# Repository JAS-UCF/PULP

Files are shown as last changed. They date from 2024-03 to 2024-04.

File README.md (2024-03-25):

# PULP

KiCAD project that contains a PCB layout, in hopes of over-optimizing the GNOR race

## Gameplan

implement a basic RP2040 board

- RP2040 processor *DONE*
- compass module *DONE*
- GPS module *DONE*
- PINOUT for I2C Bus 0 & 1 *DONE*
- PINOUT for PWM out Motor_Left & Motor_Right (2x3 Pins) *DONE*
- PINOUT for 3S Battery Power (External) ; Need to add regulator to help power the board *DONE*
- PINOUT for 6 GPIO pins *DONE*
- USB-C for programming and power *DONE*

## Questions?

Join the JAS Discord : <https://discord.gg/rzfwvgsg3Z>
Ask @ Peter about the project!

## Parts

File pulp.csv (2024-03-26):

Source: | /home/shitta/projects/PULP/pulp.kicad_sch
Date: | Tue 26 Mar 2024 07:26:22 PM EDT
Tool: | Eeschema 7.0.8-7.0.8~ubuntu22.04.1
Generator: | /usr/share/kicad/plugins/bom_csv_grouped_by_value.py
Component Count: | 71
Collated Components:
Item | Qty | Reference(s) | Value | LibPart | Footprint | Datasheet | DNP | Availability | Check_prices | Description | MF | MP | PROD_ID | Package | Price | SF_ID | SnapEDA_Link
1 | 2 | C1, C3 | 0.1uF | Device:C | Capacitor_SMD:C_0201_0603Metric | ~
2 | 3 | C2, C5, C7 | 4.7uF | Device:C | Capacitor_SMD:C_0201_0603Metric | ~
3 | 1 | C4 | 10nF | Device:C | Capacitor_SMD:C_0201_0603Metric | ~
4 | 18 | C6, C8, C9, C10, C15, C16, C17, C18, C19, C20, C21, C22, C23, C24, C25, C26, C27, C28 | 1uF | Device:C | Capacitor_SMD:C_0201_0603Metric | ~
5 | 2 | D1, D2 | ESD9B5.0ST5G | Diode:ESD9B5.0ST5G | Diode_SMD:D_SOD-923 | https://www.onsemi.com/pub/Collateral/ESD9B-D.PDF
6 | 1 | D3 | LED_ARGB | Device:LED_ARGB | LED_SMD:LED_RGB_1210 | ~
7 | 1 | J1 | Conn_Coaxial | Connector:Conn_Coaxial | Connector_Coaxial:SMA_Amphenol_901-143_Horizontal | ~
8 | 2 | J2, J3 | Conn_01x02_Pin | Connector:Conn_01x02_Pin | Connector_PinHeader_2.54mm:PinHeader_1x02_P2.54mm_Horizontal | ~
9 | 2 | J4, J5 | Conn_01x03_Pin | Connector:Conn_01x03_Pin | Connector_PinHeader_2.54mm:PinHeader_1x03_P2.54mm_Horizontal | ~
10 | 1 | J6 | Conn_01x09_Pin | Connector:Conn_01x09_Pin | Connector_PinHeader_2.54mm:PinHeader_1x09_P2.54mm_Vertical | ~
11 | 1 | J7 | USB_C_Receptacle | Connector:USB_C_Receptacle | Connector_USB:USB_C_Receptacle_CNCTech_C-ARA1-AK51X | https://www.usb.org/sites/default/files/documents/usb_type-c.zip
12 | 1 | J8 | Conn_01x02_Pin | Connector:Conn_01x02_Pin | Connector_AMASS:AMASS_XT60-F_1x02_P7.20mm_Vertical | ~
13 | 1 | L1 | 27nH | Device:L | Inductor_SMD:L_0201_0603Metric | ~
14 | 3 | Q1, Q2, Q3 | BSS138 | Transistor_FET:BSS138 | Package_TO_SOT_SMD:SOT-23 | https://www.onsemi.com/pub/Collateral/BSS138-D.PDF
15 | 2 | R1, R2 | 4.7K | Device:R | Resistor_SMD:R_0201_0603Metric | ~
16 | 1 | R3 | 10 | Device:R | Resistor_SMD:R_0201_0603Metric | ~
17 | 2 | R4, R5 | 5.1K | Device:R | Resistor_SMD:R_0201_0603Metric | ~
18 | 3 | R6, R10, R11 | 10K | Device:R | Resistor_SMD:R_0201_0603Metric | ~
19 | 2 | R7, R8 | 1K | Device:R | Resistor_SMD:R_0201_0603Metric | ~
20 | 3 | R9, R19, R20 | 510 | Device:R | Resistor_SMD:R_0201_0603Metric | ~
21 | 10 | R12, R13, R14, R15, R16, R17, R18, R21, R22, R23 | 27 | Device:R | Resistor_SMD:R_0201_0603Metric | ~
22 | 2 | SW1, SW2 | SW_Push | Switch:SW_Push | Button_Switch_SMD:SW_Push_SPST_NO_Alps_SKRK | ~
23 | 1 | U1 | HMC5883L | HMC5883L:HMC5883L | Sensor:HMC5883L |  |  | In Stock | https://www.snapeda.com/parts/HMC5883L-T/Honeywell+Aerospace/view-part/?ref=eda | Magnetoresistive Sensor X, Y, Z Axis 16-LCC | Honeywell Aerospace | HMC5883L-T | IC-10284 | LCC-16 Honeywell | None | COM-10494 | https://www.snapeda.com/parts/HMC5883L-T/Honeywell+Aerospace/view-part/?ref=snap
24 | 1 | U2 | RP2040 | MCU_RaspberryPi:RP2040 | Package_DFN_QFN:QFN-56-1EP_7x7mm_P0.4mm_EP3.2x3.2mm | https://datasheets.raspberrypi.com/rp2040/rp2040-datasheet.pdf
25 | 1 | U3 | MAX-M8Q | RF_GPS:MAX-M8Q | RF_GPS:ublox_MAX | https://www.u-blox.com/sites/default/files/MAX-M8-FW3_DataSheet_%28UBX-15031506%29.pdf
26 | 1 | U4 | AP7361C-33E | Regulator_Linear:AP7361C-33E | Package_TO_SOT_SMD:SOT-223-3_TabPin2 | https://www.diodes.com/assets/Datasheets/AP7361C.pdf
27 | 1 | U5 | W25Q128JVS | Memory_Flash:W25Q128JVS | Package_SO:SOIC-8_5.23x5.23mm_P1.27mm | http://www.winbond.com/resource-files/w25q128jv_dtr%20revc%2003272018%20plus.pdf
28 | 1 | U6 | BD33FC0FP | Regulator_Linear:BD33FC0FP | Package_TO_SOT_SMD:TO-252-2 | https://fscdn.rohm.com/en/products/databook/datasheet/ic/power/linear_regulator/bdxxfc0wefj-e.pdf
29 | 1 | X2 | ASE-12.0MHz | Oscillator:ASE-xxxMHz | Oscillator:Oscillator_SMD_Abracon_ASE-4Pin_3.2x2.5mm | http://www.abracon.com/Oscillators/ASV.pdf

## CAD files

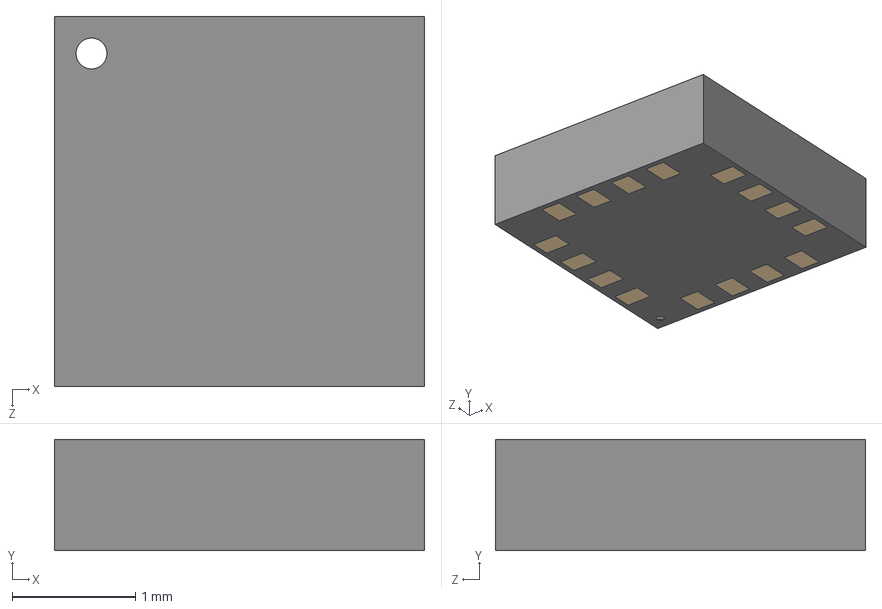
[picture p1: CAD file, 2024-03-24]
Special_Footprints/HMC5883L/HMC5883L.step
3.00 x 0.9 x 3.00 mm

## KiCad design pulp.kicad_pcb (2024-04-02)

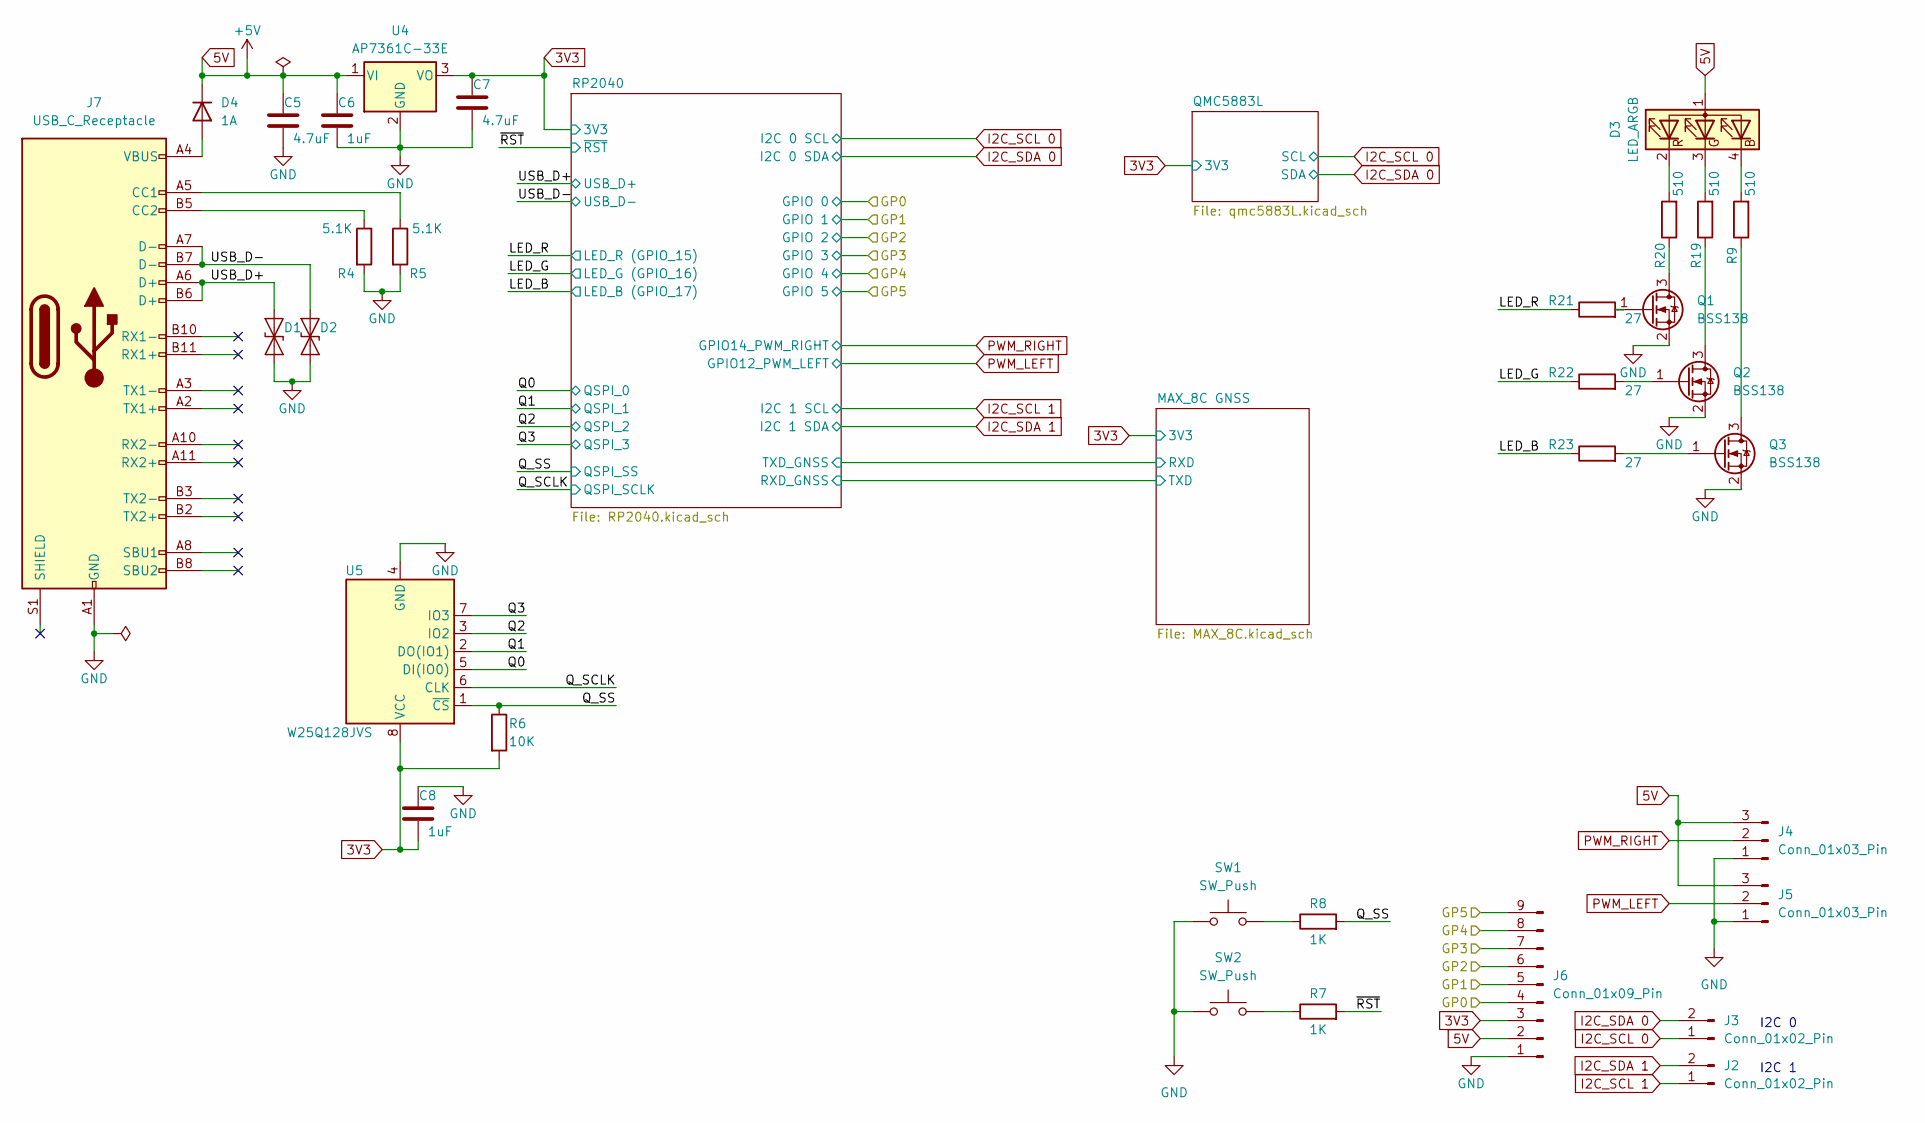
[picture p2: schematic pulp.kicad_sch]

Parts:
C5, C7: 4.7uF; C_0201_0603Metric
C6, C8: 1uF; C_0201_0603Metric
D1, D2: ESD9B5.0ST5G; D_SOD-923
D3: LED_ARGB; LED_RGB_1210
D4: 1A; D_1812_4532Metric
J2, J3: Conn_01x02_Pin; PinHeader_1x02_P2.54mm_Horizontal
J4, J5: Conn_01x03_Pin; PinHeader_1x03_P2.54mm_Horizontal
J6: Conn_01x09_Pin; PinHeader_1x09_P2.54mm_Vertical
J7: USB_C_Receptacle; USB_C_Receptacle_CNCTech_C-ARA1-AK51X
Q1, Q2, Q3: BSS138; SOT-23
R4, R5: 5.1K; R_0201_0603Metric
R6: 10K; R_0201_0603Metric
R7, R8: 1K; R_0201_0603Metric
R9, R19, R20: 510; R_0201_0603Metric
R21, R22, R23: 27; R_0201_0603Metric
SW1, SW2: SW_Push; SW_Push_SPST_NO_Alps_SKRK
U4: AP7361C-33E; SOT-223-3_TabPin2
U5: W25Q128JVS; SOIC-8_5.23x5.23mm_P1.27mm

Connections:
3V3: C7.1, C8.2, J6.3, R6.2, U4.3 (VO), U5.8 (VCC); also elsewhere on the board
5V: C5.1, C6.1, D3.1 (A), D4.1 (K), J4.3, J5.3, J6.2, U4.1 (VI)
/GP0: J6.4; also elsewhere on the board
/GP1: J6.5; also elsewhere on the board
/GP2: J6.6; also elsewhere on the board
/GP3: J6.7; also elsewhere on the board
/GP4: J6.8; also elsewhere on the board
/GP5: J6.9; also elsewhere on the board
/LED_B: R23.1; also elsewhere on the board
/LED_G: R22.1; also elsewhere on the board
/LED_R: R21.1; also elsewhere on the board
/Q0: U5.5 (DI(IO0)); also elsewhere on the board
/Q1: U5.2 (DO(IO1)); also elsewhere on the board
/Q2: U5.3 (IO2); also elsewhere on the board
/Q3: U5.7 (IO3); also elsewhere on the board
/Q_SCLK: U5.6 (CLK); also elsewhere on the board
/Q_SS: R6.1, R8.2, U5.1 (~CS); also elsewhere on the board
/USB_D+: D1.2 (A2), J7.A6 (D+), J7.B6 (D+); also elsewhere on the board
/USB_D-: D2.2 (A2), J7.A7 (D-), J7.B7 (D-); also elsewhere on the board
/~RST: R7.2; also elsewhere on the board
GND: C5.2, C6.2, C7.2, C8.1, D1.1 (A1), D2.1 (A1), J4.1, J5.1, J6.1, J7.A1 (GND), J7.A12 (GND), J7.B1 (GND), J7.B12 (GND), Q1.2 (S), Q2.2 (S), Q3.2 (S), R4.2, R5.2, SW1.1, SW2.1, U4.2 (GND), U5.4 (GND); also elsewhere on the board
I2C_SCL 0: J3.1; also elsewhere on the board
I2C_SCL 1: J2.1; also elsewhere on the board
I2C_SDA 0: J3.2; also elsewhere on the board
I2C_SDA 1: J2.2; also elsewhere on the board
unnamed: D3.4 (BK), R9.2
unnamed: D3.3 (GK), R19.2
unnamed: D3.2 (RK), R20.2
unnamed: D4.2 (A), J7.A4 (VBUS), J7.A9 (VBUS), J7.B4 (VBUS), J7.B9 (VBUS)
unnamed: J7.A5 (CC1), R5.1
unnamed: J7.B5 (CC2), R4.1
unnamed: Q1.3 (D), R20.1
unnamed: Q1.1 (G), R21.2
unnamed: Q2.3 (D), R19.1
unnamed: Q2.1 (G), R22.2
unnamed: Q3.3 (D), R9.1
unnamed: Q3.1 (G), R23.2
unnamed: R7.1, SW2.2
unnamed: R8.1, SW1.2
PWM_LEFT: J5.2; also elsewhere on the board
PWM_RIGHT: J4.2; also elsewhere on the board

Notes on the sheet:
I2C 0
I2C 1

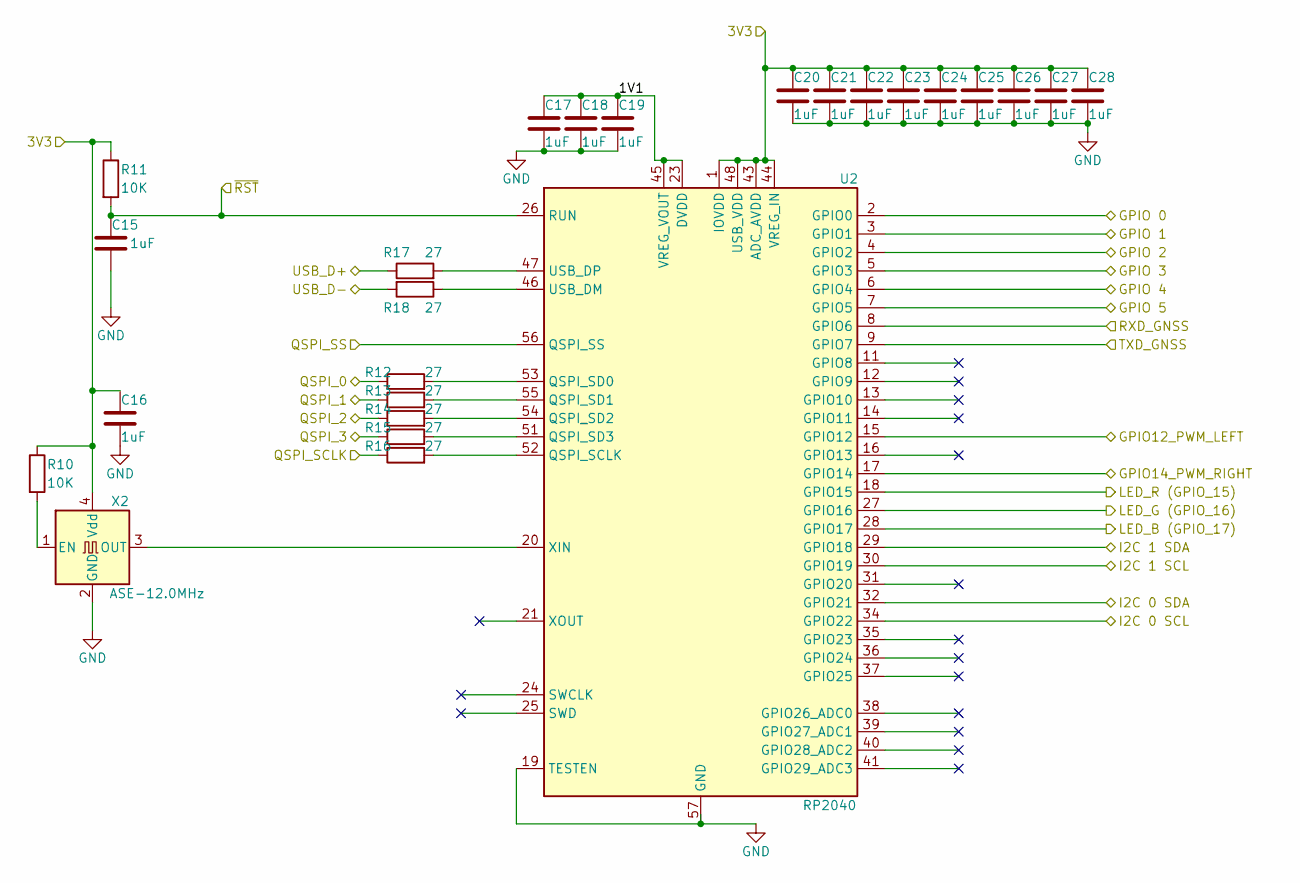
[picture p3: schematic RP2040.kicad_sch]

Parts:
C15, C16, C17, C18, C19, C20, C21, C22, C23, C24, C25, C26, C27, C28: 1uF; C_0201_0603Metric
R10, R11: 10K; R_0201_0603Metric
R12, R13, R14, R15, R16, R17, R18: 27; R_0201_0603Metric
U2: RP2040; QFN-56-1EP_7x7mm_P0.4mm_EP3.2x3.2mm
X2: ASE-12.0MHz; Oscillator_SMD_Abracon_ASE-4Pin_3.2x2.5mm

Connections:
3V3: C16.1, C20.1, C21.1, C22.1, C23.1, C24.1, C25.1, C26.1, C27.1, C28.1, R10.1, R11.1, U2.1 (IOVDD), U2.10 (IOVDD), U2.22 (IOVDD), U2.33 (IOVDD), U2.42 (IOVDD), U2.43 (ADC_AVDD), U2.44 (VREG_IN), U2.48 (USB_VDD), U2.49 (IOVDD), X2.4 (Vdd); also elsewhere on the board
/GP0: U2.2 (GPIO0); also elsewhere on the board
/GP1: U2.3 (GPIO1); also elsewhere on the board
/GP2: U2.4 (GPIO2); also elsewhere on the board
/GP3: U2.5 (GPIO3); also elsewhere on the board
/GP4: U2.6 (GPIO4); also elsewhere on the board
/GP5: U2.7 (GPIO5); also elsewhere on the board
/LED_B: U2.28 (GPIO17); also elsewhere on the board
/LED_G: U2.27 (GPIO16); also elsewhere on the board
/LED_R: U2.18 (GPIO15); also elsewhere on the board
/MAX_8C GNSS/RXD: U2.9 (GPIO7); also elsewhere on the board
/MAX_8C GNSS/TXD: U2.8 (GPIO6); also elsewhere on the board
/Q0: R12.1; also elsewhere on the board
/Q1: R13.1; also elsewhere on the board
/Q2: R14.1; also elsewhere on the board
/Q3: R15.1; also elsewhere on the board
/Q_SCLK: R16.1; also elsewhere on the board
/Q_SS: U2.56 (QSPI_SS); also elsewhere on the board
/RP2040/1V1: C17.1, C18.1, C19.1, U2.23 (DVDD), U2.45 (VREG_VOUT), U2.50 (DVDD)
/USB_D+: R17.1; also elsewhere on the board
/USB_D-: R18.2; also elsewhere on the board
/~RST: C15.1, R11.2, U2.26 (RUN); also elsewhere on the board
GND: C15.2, C16.2, C17.2, C18.2, C19.2, C20.2, C21.2, C22.2, C23.2, C24.2, C25.2, C26.2, C27.2, C28.2, U2.19 (TESTEN), U2.57 (GND), X2.2 (GND); also elsewhere on the board
I2C_SCL 0: U2.34 (GPIO22); also elsewhere on the board
I2C_SCL 1: U2.30 (GPIO19); also elsewhere on the board
I2C_SDA 0: U2.32 (GPIO21); also elsewhere on the board
I2C_SDA 1: U2.29 (GPIO18); also elsewhere on the board
unnamed: R16.2, U2.52 (QSPI_SCLK)
unnamed: R12.2, U2.53 (QSPI_SD0)
unnamed: R13.2, U2.55 (QSPI_SD1)
unnamed: R14.2, U2.54 (QSPI_SD2)
unnamed: R15.2, U2.51 (QSPI_SD3)
unnamed: R18.1, U2.46 (USB_DM)
unnamed: R17.2, U2.47 (USB_DP)
unnamed: U2.20 (XIN), X2.3 (OUT)
unnamed: R10.2, X2.1 (EN)
PWM_LEFT: U2.15 (GPIO12); also elsewhere on the board
PWM_RIGHT: U2.17 (GPIO14); also elsewhere on the board

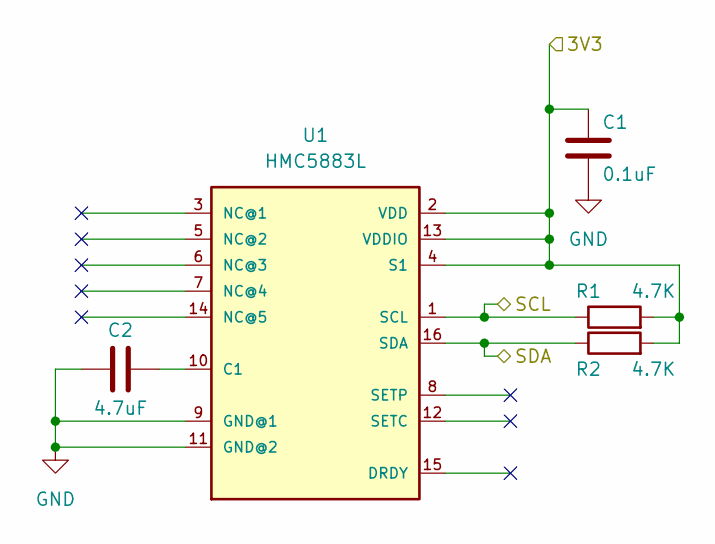
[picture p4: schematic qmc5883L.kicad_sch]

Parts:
C1: 0.1uF; C_0201_0603Metric
C2: 4.7uF; C_0201_0603Metric
R1, R2: 4.7K; R_0201_0603Metric
U1: HMC5883L

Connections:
3V3: C1.1, R1.2, R2.2, U1.2 (VDD), U1.4 (S1), U1.13 (VDDIO); also elsewhere on the board
GND: C1.2, C2.1, U1.9 (GND@1), U1.11 (GND@2); also elsewhere on the board
I2C_SCL 0: R1.1, U1.1 (SCL); also elsewhere on the board
I2C_SDA 0: R2.1, U1.16 (SDA); also elsewhere on the board
unnamed: C2.2, U1.10 (C1)

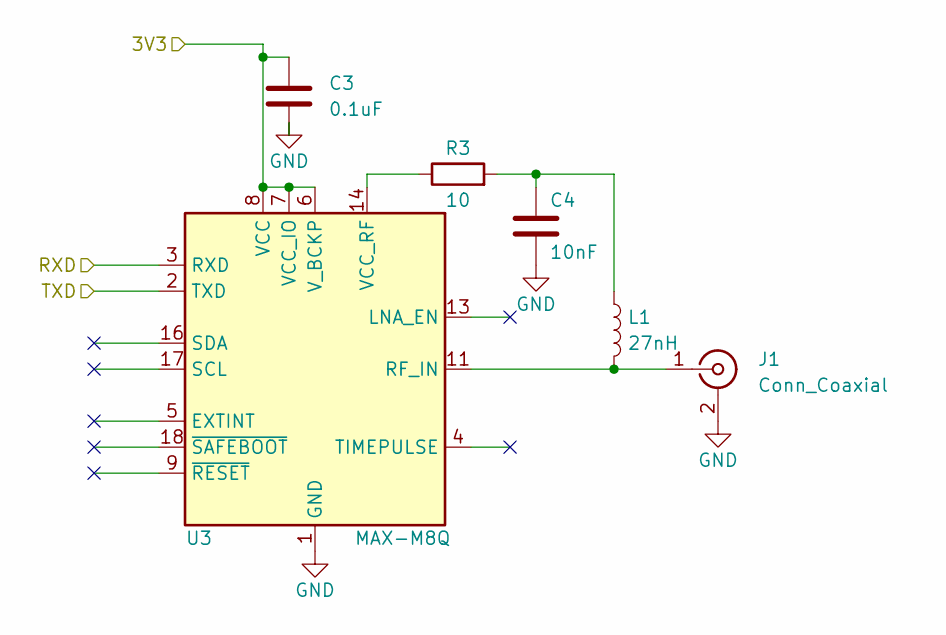
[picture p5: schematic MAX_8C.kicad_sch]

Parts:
C3: 0.1uF; C_0201_0603Metric
C4: 10nF; C_0201_0603Metric
J1: Conn_Coaxial; U.FL_Molex_MCRF_73412-0110_Vertical
L1: 27nH; L_0201_0603Metric
R3: 10; R_0201_0603Metric
U3: MAX-M8Q; ublox_MAX

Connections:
3V3: C3.1, U3.6 (V_BCKP), U3.7 (VCC_IO), U3.8 (VCC); also elsewhere on the board
/MAX_8C GNSS/RXD: U3.3 (RXD); also elsewhere on the board
/MAX_8C GNSS/TXD: U3.2 (TXD); also elsewhere on the board
GND: C3.2, C4.2, J1.2 (Ext), U3.1 (GND), U3.10 (GND), U3.12 (GND); also elsewhere on the board
unnamed: C4.1, L1.1, R3.2
unnamed: J1.1 (In), L1.2, U3.11 (RF_IN)
unnamed: R3.1, U3.14 (VCC_RF)

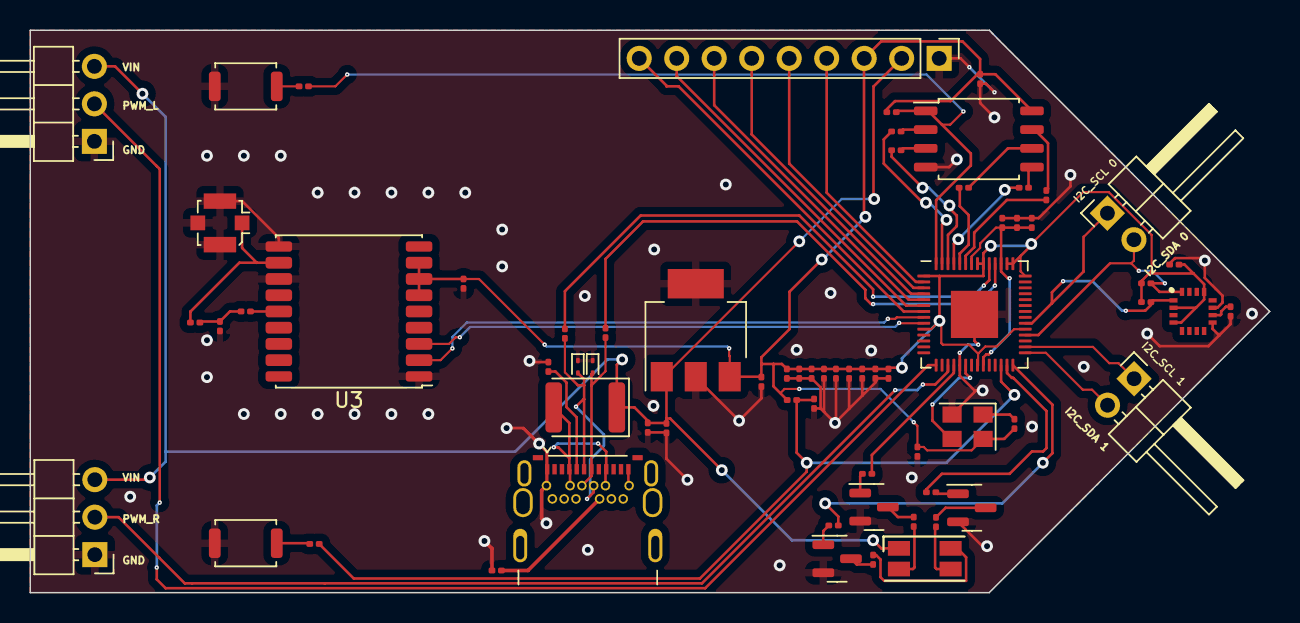
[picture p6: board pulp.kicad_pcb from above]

Board: 2 copper layers, 84.0 x 38.1 mm, 68 parts (0 on the bottom side), 57 nets.

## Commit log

2024-03-23 pulp beginnings using RP2040
    [pulp.kicad_pcb, pulp.kicad_sch, untitled.kicad_sch]
2024-03-23 exposes proper GPIO
    [pulp.kicad_sch, untitled.kicad_sch]
2024-03-23 switching to a more sane lisence
2024-03-23 final save of day 1
    [untitled.kicad_sch]
2024-03-23 adds 2 new PWM PINS for the Motors
    [pulp.csv, pulp.kicad_sch, untitled.kicad_sch]
2024-03-23 refine project scope
    [pulp.kicad_sch]
2024-03-23 started PCB layout
    [pulp.kicad_pcb, untitled.kicad_sch]
2024-03-24 made edits to PWM
    [pulp.kicad_pcb]
2024-03-24 adds QMC5883L
    [HMC5883L.step, pulp.kicad_pcb, pulp.kicad_sch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]
2024-03-25 adds GNSS module
    [MAX_8C.kicad_sch, RP2040.kicad_sch, pulp.kicad_sch]
2024-03-25 finalized a lot of sub-modules
    [MAX_8C.kicad_sch, RP2040.kicad_sch, pulp.kicad_sch]
2024-03-25 NO ERC ERRORS!!!!
    [MAX_8C.kicad_sch, RP2040.kicad_sch, pulp.kicad_pcb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]
2024-03-25 Finalized voltage regulator for Battery
    [pulp.kicad_sch]
2024-03-26 begins PCB routing for the final design V1
    [battery_regulator.kicad_sch, pulp.kicad_pcb, pulp.kicad_sch]
2024-03-26 edits to pcb board
    [pulp.csv, pulp.kicad_pcb]
2024-03-30 finished pcb layout
    [MAX_8C.kicad_sch, RP2040.kicad_sch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]
2024-04-02 agged ground VIA to help remove island
    [pulp.kicad_pcb]
